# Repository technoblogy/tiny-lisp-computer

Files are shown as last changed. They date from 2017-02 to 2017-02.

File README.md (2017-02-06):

# Tiny Lisp Computer
A self-contained computer with its own display and keyboard, based on an ATmega328 or ATmega1284, that you can program in Lisp.
For more information see:

Tiny Lisp Computer (ATmega328): http://www.technoblogy.com/show?1GX1

Tiny Lisp Computer 2 (ATmega1284): http://www.technoblogy.com/show?1INT

Tiny Lisp Computer 2 PCB version: http://www.technoblogy.com/show?1KTO

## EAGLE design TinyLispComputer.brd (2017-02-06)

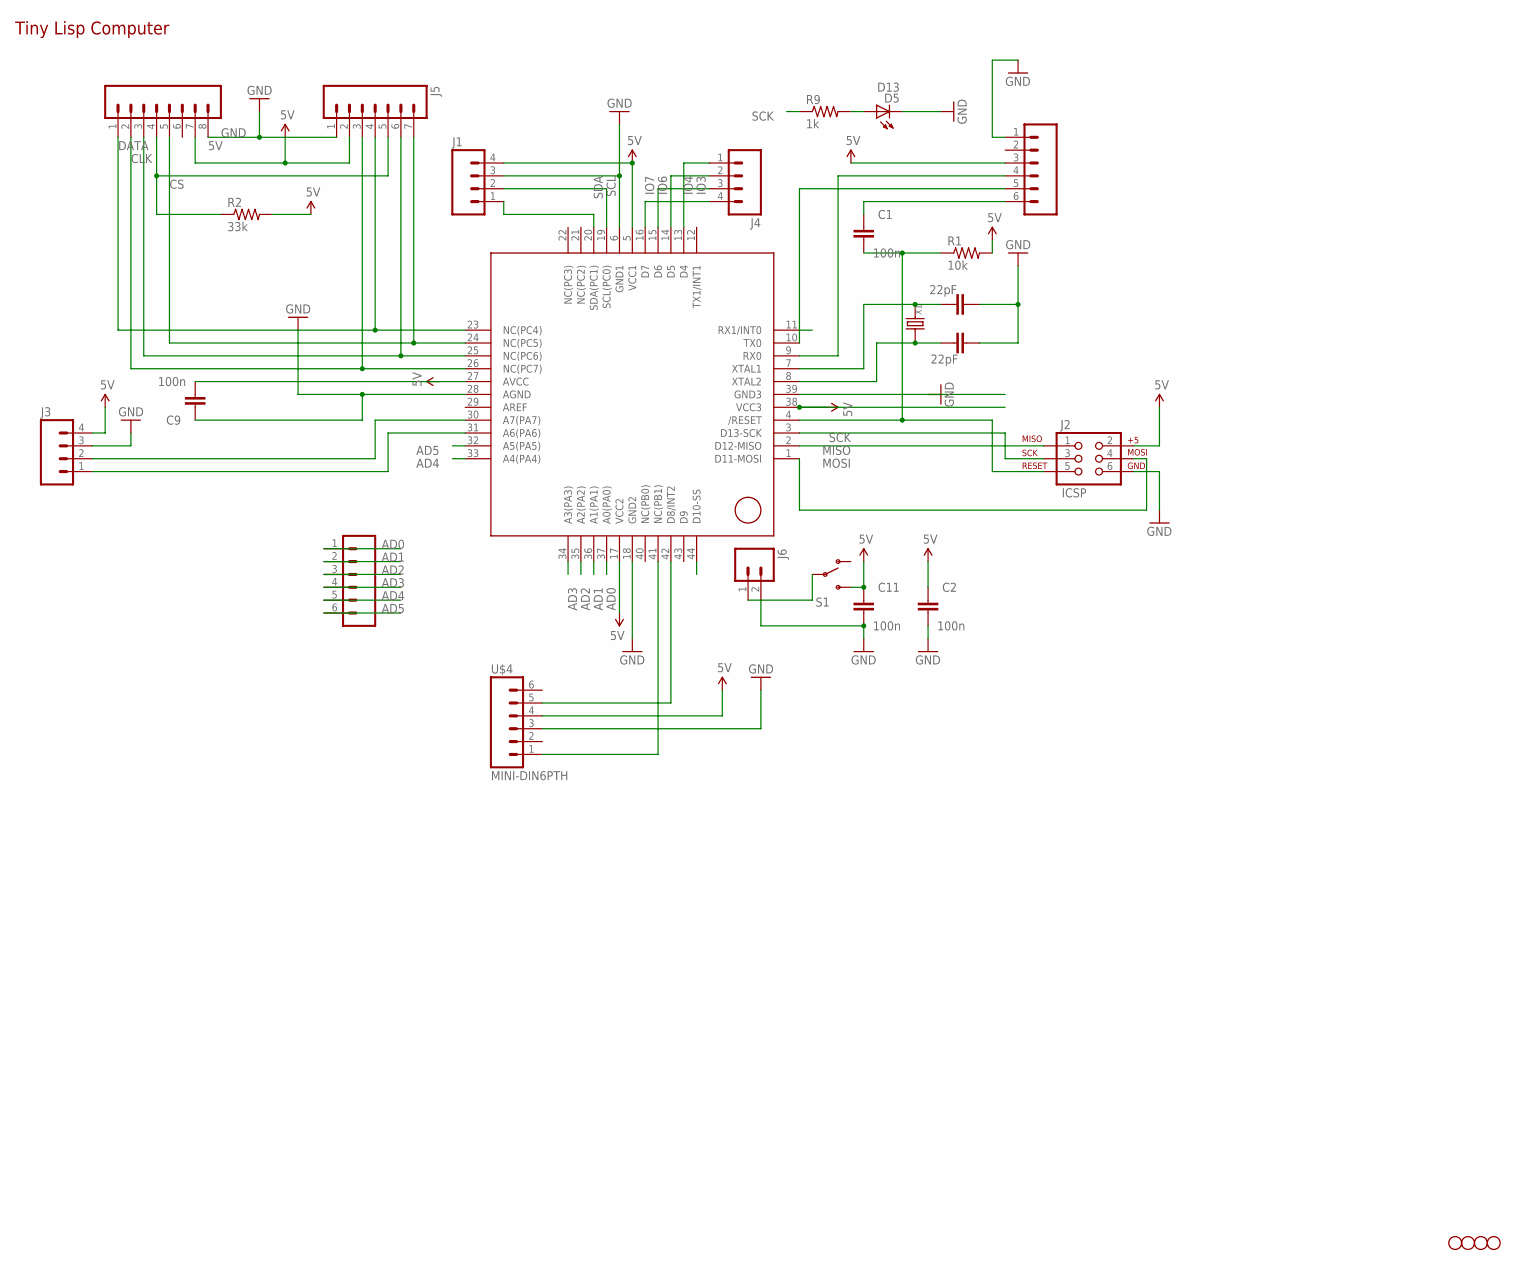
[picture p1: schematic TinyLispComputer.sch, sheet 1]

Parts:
C1, C2, C9, C11: 100n; 0603-CAP
C12, C13: 22pF; 0603-CAP
D5: D13; CHIPLED_0805
J1, J3, J4: M04LONGPADS; 1X04_LONGPADS
J2: ICSP; 2X3
J5: M07; 1X07
J6: M021X02_NO_SILK; 1X02_NO_SILK
JP1, JP11: M06LONGPADS; 1X06_LONGPADS
JP3, JP4, JP5, JP6: STAND-OFF
OLED: M08; 1X08_ROUND
R1: 10k; 0805
R2: 33k; 0805
R9: 1k; 0805
S1: SWITCH-SPDTPTH; SWITCH-SPDT
U3: ATMEGA1284P; TQFP44
U$4: MINI-DIN6PTH; MINI-DIN6
X1: CRYSTAL-0500290P1; 2P-SMD-5.0X3.2

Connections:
5V: C2.1, C9.2, C11.1, J1.4, J2.2, J3.4, J5.2, JP1.3, OLED.7, R1.2, R2.2, S1.3 (S), U3.5 (VCC1), U3.17 (VCC2), U3.27 (AVCC), U3.38 (VCC3), U$4.4
AD0: JP11.1, U3.37 (A0(PA0))
AD1: JP11.2, U3.36 (A1(PA1))
AD2: JP11.3, U3.35 (A2(PA2))
AD3: JP11.4, U3.34 (A3(PA3))
AD4: JP11.5, U3.33 (A4(PA4))
AD5: JP11.6, U3.32 (A5(PA5))
CLK: J5.6, OLED.3, U3.25 (NC(PC6))
CS: J5.4, OLED.1, U3.23 (NC(PC4))
DATA: J5.3, OLED.2, U3.26 (NC(PC7))
GND: C2.2, C9.1, C11.2, C12.1, C13.1, D5.C, J1.3, J2.6, J3.3, J5.1, J6.2, JP1.1, OLED.8, U3.6 (GND1), U3.18 (GND2), U3.28 (AGND), U3.39 (GND3), U$4.3
IO2: U3.11 (RX1/INT0)
IO3: J4.1, U3.13 (D4)
IO4: J4.2, U3.14 (D5)
IO6: J4.3, U3.15 (D6)
IO7: J4.4, U3.16 (D7)
MISO: J2.1, U3.2 (D12-MISO)
MOSI: J2.4, U3.1 (D11-MOSI)
unnamed: J5.7, OLED.5, U3.24 (NC(PC5))
unnamed: J6.1, S1.2
unnamed: C1.1, JP1.6
unnamed: J5.5, OLED.4, R2.1
unnamed: J3.1, U3.31 (A6(PA6))
unnamed: C1.2, J2.5, R1.1, U3.4 (/RESET)
unnamed: U3.42 (D8/INT2), U$4.5
unnamed: U3.41 (NC(PB1)), U$4.1
unnamed: J3.2, U3.30 (A7(PA7))
unnamed: D5.A, R9.2
unnamed: C13.2, U3.8 (XTAL2), X1.2
unnamed: C12.2, U3.7 (XTAL1), X1.1
RX-I: JP1.4, U3.9 (RX0)
SCK: J2.3, R9.1, U3.3 (D13-SCK)
SCL: J1.2, U3.19 (SCL(PC0))
SDA: J1.1, U3.20 (SDA(PC1))
SS: U3.44 (D10-SS)
TX-O: JP1.5, U3.10 (TX0)

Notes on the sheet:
Tiny Lisp Computer

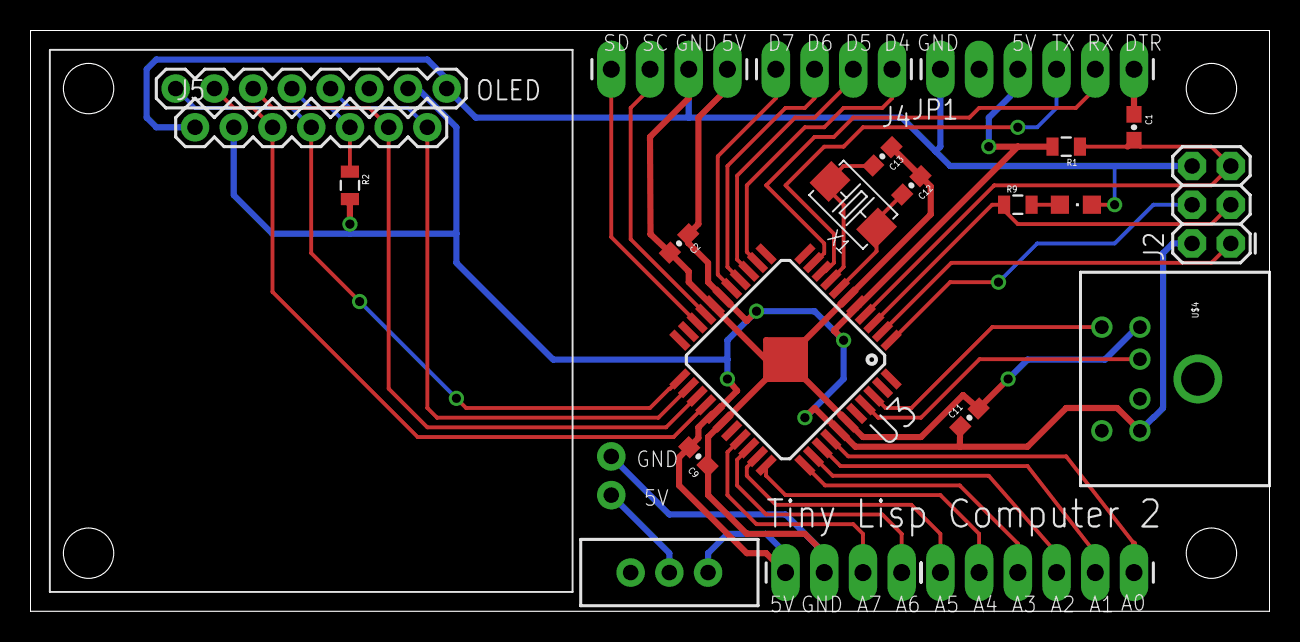
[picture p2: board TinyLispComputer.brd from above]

Board: 2 copper layers, 81.3 x 38.1 mm, 27 parts (0 on the bottom side), 34 nets.

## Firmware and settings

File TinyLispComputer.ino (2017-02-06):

 /* Tiny Lisp Computer 2 - uLisp 1.5
   David Johnson-Davies - www.technoblogy.com - 24th January 2017
    
   Licensed under the MIT license: https://opensource.org/licenses/MIT
*/

#include <setjmp.h>
#include <SPI.h>

// Compile options

#define checkoverflow
#define resetautorun
// #define printfreespace
#define serialmonitor
#define tinylispcomputer

// C Macros

#define nil                NULL
#define car(x)             (((object *) (x))->car)
#define cdr(x)             (((object *) (x))->cdr)

#define first(x)           (((object *) (x))->car)
#define second(x)          (car(cdr(x)))
#define cddr(x)            (cdr(cdr(x)))
#define third(x)           (car(cdr(cdr(x))))
#define fourth(x)          (car(cdr(cdr(cdr(x)))))

#define push(x, y)         ((y) = cons((x),(y)))
#define pop(y)             ((y) = cdr(y))

#define numberp(x)         ((x)->type == NUMBER)
#define stringp(x)         ((x)->type == STRING)
#define streamp(x)         ((x)->type == STREAM)
#define listp(x)           ((x) == NULL || (x)->type >= PAIR || (x)->type == ZERO)
#define consp(x)           (((x)->type >= PAIR || (x)->type == ZERO) && (x) != NULL)

#define mark(x)            (car(x) = (object *)(((unsigned int)(car(x))) | 0x8000))
#define unmark(x)          (car(x) = (object *)(((unsigned int)(car(x))) & 0x7FFF))
#define marked(x)          ((((unsigned int)(car(x))) & 0x8000) != 0)

// 1:Show GCs 2:show symbol addresses
// #define debug1
// #define debug2

// Constants
// RAMSTART, RAMEND, and E2END are defined by the processor's ioxxx.h file

const int RAMsize = RAMEND - RAMSTART + 1;
const int workspacesize = (RAMsize - RAMsize/4 - 280)/4;
const int EEPROMsize = E2END;

const int buflen = 17;  // Length of longest symbol + 1
enum type {ZERO, SYMBOL, NUMBER, STRING, STREAM, PAIR };  // PAIR must be last
enum token { UNUSED, BRA, KET, QUO, DOT };
enum stream { SERIALSTREAM, I2CSTREAM, SPISTREAM };

enum function { SYMBOLS, NIL, TEE, LAMBDA, LET, LETSTAR, CLOSURE, SPECIAL_FORMS, QUOTE, DEFUN, DEFVAR,
SETQ, LOOP, PUSH, POP, INCF, DECF, SETF, DOLIST, DOTIMES, FORMILLIS, WITHI2C, WITHSPI, TAIL_FORMS, PROGN,
RETURN, IF, COND, WHEN, UNLESS, AND, OR, FUNCTIONS, NOT, NULLFN, CONS, ATOM, LISTP, CONSP, NUMBERP,
STREAMP, EQ, CAR, FIRST, CDR, REST, CAAR, CADR, SECOND, CDAR, CDDR, CAAAR, CAADR, CADAR, CADDR, THIRD,
CDAAR, CDADR, CDDAR, CDDDR, LENGTH, LIST, REVERSE, NTH, ASSOC, MEMBER, APPLY, FUNCALL, APPEND, MAPC,
MAPCAR, ADD, SUBTRACT, MULTIPLY, DIVIDE, MOD, ONEPLUS, ONEMINUS, ABS, RANDOM, MAX, MIN, NUMEQ, LESS,
LESSEQ, GREATER, GREATEREQ, NOTEQ, PLUSP, MINUSP, ZEROP, ODDP, EVENP, STRINGP, STRINGEQ, SUBSEQ, LOGAND,
LOGIOR, LOGXOR, LOGNOT, ASH, LOGBITP, READ, EVAL, GLOBALS, LOCALS, MAKUNBOUND, BREAK, PRINT, PRINC,
WRITEBYTE, READBYTE, RESTARTI2C, GC, ROOM, SAVEIMAGE, LOADIMAGE, CLS, PINMODE, DIGITALREAD, DIGITALWRITE,
ANALOGREAD, ANALOGWRITE, DELAY, MILLIS, NOTE, EDIT, ENDFUNCTIONS };

// Typedefs

typedef struct sobject {
  union {
    struct {
      sobject *car;
      sobject *cdr;
    };
    struct {
      enum type type;
      union {
        unsigned int name;
        int integer;
      };
    };
  };
} object;

typedef object *(*fn_ptr_type)(object *, object *);

typedef struct {
  const char *string;
  fn_ptr_type fptr;
  int min;
  int max;
} tbl_entry_t;

// Global variables

jmp_buf exception;
object workspace[workspacesize];
unsigned int freespace = 0;
char ReturnFlag = 0;
object *freelist;
extern uint8_t _end;
int i2cCount;

object *GlobalEnv;
object *GCStack = NULL;
char buffer[buflen+1];
char BreakLevel = 0;
char LastChar = 0;
char LastPrint = 0;
volatile char Escape = 0;
char ExitEditor = 0;
char PrintReadably = 1;

// Forward references
object *tee;
object *tf_progn (object *form, object *env);
object *eval (object *form, object *env);
object *read ();
void repl(object *env);
void printobject (object *form);
char *lookupstring (unsigned int name);
int lookupfn (unsigned int name);
int builtin (char* n);
void Display (char c);

// Set up workspace

void initworkspace () {
  freelist = NULL;
  for (int i=workspacesize-1; i>=0; i--) {
    object *obj = &workspace[i];
    car(obj) = NULL;
    cdr(obj) = freelist;
    freelist = obj;
    freespace++;
  }
}

object *myalloc () {
  if (freespace == 0) error(F("No room"));
  object *temp = freelist;
  freelist = cdr(freelist);
  freespace--;
  return temp;
}

inline void myfree (object *obj) {
  car(obj) = NULL;
  cdr(obj) = freelist;
  freelist = obj;
  freespace++;
}

// Make each type of object

object *number (int n) {
  object *ptr = myalloc();
  ptr->type = NUMBER;
  ptr->integer = n;
  return ptr;
}

object *cons (object *arg1, object *arg2) {
  object *ptr = myalloc();
  ptr->car = arg1;
  ptr->cdr = arg2;
  return ptr;
}

object *symbol (unsigned int name) {
  object *ptr = myalloc();
  ptr->type = SYMBOL;
  ptr->name = name;
  return ptr;
}

object *stream (unsigned char streamtype, unsigned char address) {
  object *ptr = myalloc();
  ptr->type = STREAM;
  ptr->integer = streamtype<<8 | address;
  return ptr;
}

// Garbage collection

void markobject (object *obj) {
  MARK:
  if (obj == NULL) return;
  if (marked(obj)) return;

  object* arg = car(obj);
  int type = obj->type;
  mark(obj);
  
  if (type >= PAIR || type == ZERO) { // cons
    markobject(arg);
    obj = cdr(obj);
    goto MARK;
  }

  if (type == STRING) {
    obj = cdr(obj);
    while (obj != NULL) {
      arg = car(obj);
      mark(obj);
      obj = arg;
    }
  }
}

void sweep () {
  freelist = NULL;
  freespace = 0;
  for (int i=workspacesize-1; i>=0; i--) {
    object *obj = &workspace[i];
    if (!marked(obj)) myfree(obj); else unmark(obj);
  }
}

void gc (object *form, object *env) {
  #if defined(debug1)
  int start = freespace;
  #endif
  markobject(tee); 
  markobject(GlobalEnv);
  markobject(GCStack);
  markobject(form);
  markobject(env);
  sweep();
  #if defined(debug1)
  pchar('{');
  pint(freespace - start);
  pchar('}');
  #endif
}

// Save-image and load-image

typedef struct {
  unsigned int eval;
  unsigned int datasize;
  unsigned int globalenv;
  unsigned int tee;
  char data[];
} struct_image;

struct_image EEMEM image;

void movepointer (object *from, object *to) {
  for (int i=0; i<workspacesize; i++) {
    object *obj = &workspace[i];
    int type = (obj->type) & 0x7FFF;
    if (marked(obj) && type >= PAIR) {
      if (car(obj) == (object *)((unsigned int)from | 0x8000)) 
        car(obj) = (object *)((unsigned int)to | 0x8000);
      if (cdr(obj) == from) cdr(obj) = to;
    }
  }
}
  
int compactimage (object **arg) {
  markobject(tee);
  markobject(GlobalEnv);
  markobject(GCStack);
  object *firstfree = workspace;
  while (marked(firstfree)) firstfree++;

  for (int i=0; i<workspacesize; i++) {
    object *obj = &workspace[i];
    if (marked(obj) && firstfree < obj) {
      car(firstfree) = car(obj);
      cdr(firstfree) = cdr(obj);
      unmark(obj);
      movepointer(obj, firstfree);
      if (GlobalEnv == obj) GlobalEnv = firstfree;
      if (GCStack == obj) GCStack = firstfree;
      if (tee == obj) tee = firstfree;
      if (*arg == obj) *arg = firstfree;
      while (marked(firstfree)) firstfree++;
    }
  }
  sweep();
  return firstfree - workspace;
}
  
int saveimage (object *arg) {
  unsigned int imagesize = compactimage(&arg);
  // Save to EEPROM
  if ((imagesize*4+8) > EEPROMsize) {
    pfstring(F("Error: Image size too large: "));
    pint(imagesize+2); pln();
    GCStack = NULL;
    longjmp(exception, 1);
  }
  eeprom_write_word(&image.datasize, imagesize);
  eeprom_write_word(&image.eval, (unsigned int)arg);
  eeprom_write_word(&image.globalenv, (unsigned int)GlobalEnv);
  eeprom_write_word(&image.tee, (unsigned int)tee);
  eeprom_write_block(workspace, image.data, imagesize*4);
  return imagesize+2;
}

int loadimage () {
  unsigned int imagesize = eeprom_read_word(&image.datasize);
  if (imagesize == 0 || imagesize == 0xFFFF) error(F("No saved image"));
  GlobalEnv = (object *)eeprom_read_word(&image.globalenv);
  tee = (object *)eeprom_read_word(&image.tee) ;
  eeprom_read_block(workspace, image.data, imagesize*4);
  gc(NULL, NULL);
  return imagesize+2;
}

// Error handling

void error (const __FlashStringHelper *string) {
  pfstring(F("Error: "));
  pfstring(string); pln();
  GCStack = NULL;
  longjmp(exception, 1);
}

void error2 (object *symbol, const __FlashStringHelper *string) {
  pfstring(F("Error: '"));
  printobject(symbol);
  pfstring(F("' "));
  pfstring(string); pln();
  GCStack = NULL;
  longjmp(exception, 1);
}

// Helper functions

int toradix40 (int ch) {
  if (ch == 0) return 0;
  if (ch >= '0' && ch <= '9') return ch-'0'+30;
  ch = ch | 0x20;
  if (ch >= 'a' && ch <= 'z') return ch-'a'+1;
  error(F("Illegal character in symbol"));
  return 0;
}

int fromradix40 (int n) {
  if (n >= 1 && n <= 26) return 'a'+n-1;
  if (n >= 30 && n <= 39) return '0'+n-30;
  if (n == 27) return '-';
  return 0;
}

int pack40 (char *buffer) {
  return (((toradix40(buffer[0]) * 40) + toradix40(buffer[1])) * 40 + toradix40(buffer[2]));
}

int digitvalue (char d) {
  if (d>='0' && d<='9') return d-'0';
  d = d | 0x20;
  if (d>='a' && d<='f') return d-'a'+10;
  return 16;
}

char *name(object *obj){
  buffer[3] = '\0';
  if(obj->type != SYMBOL) error(F("Error in name"));
  unsigned int x = obj->name;
  if (x < ENDFUNCTIONS) return lookupstring(x);
  for (int n=2; n>=0; n--) {
    buffer[n] = fromradix40(x % 40);
    x = x / 40;
  }
  return buffer;
}

int integer(object *obj){
  if(obj->type != NUMBER) error(F("not a number"));
  return obj->integer;
}

int istream(object *obj){
  if(obj->type != STREAM) error(F("not a stream"));
  return obj->integer;
}

int issymbol(object *obj, unsigned int n) {
  return obj->type == SYMBOL && obj->name == n;
}

int eq (object *arg1, object *arg2) {
  int same_object = (arg1 == arg2);
  int same_symbol = (arg1->type == SYMBOL && arg2->type == SYMBOL && arg1->name == arg2->name);
  int same_number = (arg1->type == NUMBER && arg2->type == NUMBER && arg1->integer == arg2->integer);
  return (same_object || same_symbol || same_number);
}

// Lookup variable in environment

object *value(unsigned int n, object *env) {
  while (env != NULL) {
    object *item = car(env);
    if(car(item)->name == n) return item;
    env = cdr(env);
  }
  return nil;
}

object *findvalue (object *var, object *env) {
  unsigned int varname = var->name;
  object *pair = value(varname, env);
  if (pair == NULL) pair = value(varname, GlobalEnv);
  if (pair == NULL) error2(var,F("unknown variable"));
  return pair;
}

object *findtwin (object *var, object *env) {
  while (env != NULL) {
    object *pair = car(env);
    if (car(pair) == var) return pair;
    env = cdr(env);
  }
  return NULL;
}

object *closure (int tail, object *fname, object *state, object *function, object *args, object **env) {
  object *params = first(function);
  function = cdr(function);
  // Push state if not already in env
  while (state != NULL) {
    object *pair = first(state);
    if (findtwin(car(pair), *env) == NULL) push(first(state), *env);
    state = cdr(state);
  }
  // Add arguments to environment
  while (params != NULL && args != NULL) {
    object *var = first(params);
    object *value = first(args);
    if (tail) {
      object *pair = findtwin(var, *env);
      if (pair != NULL) cdr(pair) = value;
      else push(cons(var,value), *env);
    } else push(cons(var,value), *env);
    params = cdr(params);
    args = cdr(args);
  }
  if (params != NULL) error2(fname, F("has too few parameters"));
  if (args != NULL) error2(fname, F("has too many parameters"));
  // Do an implicit progn
  return tf_progn(function, *env); 
}

inline int listlength (object *list) {
  int length = 0;
  while (list != NULL) {
    list = cdr(list);
    length++;
  }
  return length;
}

inline int stringlength (object *form) {
  int length = 0;
  form = cdr(form);
  while (form != NULL) {
    int chars = form->integer;
    if (chars & 0xFF) length++;
    if (chars & 0xFF00) length++;
    form = car(form);
  }
  return length;
}

char character (object *string, int n) {
  object *arg = cdr(string);
  for (int i=0; i<(n>>1); i++) {
    if (arg == NULL) error(F("'subseq' index out of range"));
    arg = car(arg);
  }
  char ch;
  if (n&1) ch = (arg->integer) & 0xFF; else ch = (arg->integer)>>8 & 0xFF;
  if (ch == 0) error(F("'subseq' index out of range"));
  return ch;
}
  
object *apply (object *function, object *args, object **env) {
  if (function->type == SYMBOL) {
    unsigned int name = function->name;
    int nargs = listlength(args);
    if (name >= ENDFUNCTIONS) error2(function, F("is not a function"));
    if (nargs<lookupmin(name)) error2(function, F("has too few arguments"));
    if (nargs>lookupmax(name)) error2(function, F("has too many arguments"));
    return ((fn_ptr_type)lookupfn(name))(args, *env);
  }
  if (listp(function) && issymbol(car(function), LAMBDA)) {
    function = cdr(function);
    object *result = closure(1, NULL, NULL, function, args, env);
    return eval(result, *env);
  }
  if (listp(function) && issymbol(car(function), CLOSURE)) {
    function = cdr(function);
    object *result = closure(1, NULL, car(function), cdr(function), args, env);
    return eval(result, *env);
  }
  error2(function, F("illegal function"));
  return NULL;
}

// In-place operations

object **place (object *args, object *env) {
  if (!consp(args)) return &cdr(findvalue(args, env));
  object* function = first(args);
  if (issymbol(function, CAR) || issymbol(function, FIRST)) {
    object *value = eval(second(args), env);
    if (!listp(value)) error(F("Can't take car"));
    return &car(value);
  }
  if (issymbol(function, CDR) || issymbol(function, REST)) {
    object *value = eval(second(args), env);
    if (!listp(value)) error(F("Can't take cdr"));
    return &cdr(value);
  }
  if (issymbol(function, NTH)) {
    int index = integer(eval(second(args), env));
    object *list = eval(third(args), env);
    if (!consp(list)) error(F("'nth' second argument is not a list"));
    while (index > 0) {
      list = cdr(list);
      if (list == NULL) error(F("'nth' index out of range"));
      index--;
    }
    return &car(list);
  }
  error(F("Illegal place"));
  return nil;
}

// Checked car and cdr

inline object *carx (object *arg) {
  if (!listp(arg)) error(F("Can't take car"));
  if (arg == nil) return nil;
  return car(arg);
}

inline object *cdrx (object *arg) {
  if (!listp(arg)) error(F("Can't take cdr"));
  if (arg == nil) return nil;
  return cdr(arg);
}

// I2C interface

#if defined(__AVR_ATmega328P__)
uint8_t const TWI_SDA_PIN = 18;
uint8_t const TWI_SCL_PIN = 19;
#elif defined(__AVR_ATmega1280__) || defined(__AVR_ATmega2560__)
uint8_t const TWI_SDA_PIN = 20;
uint8_t const TWI_SCL_PIN = 21;
#elif defined(__AVR_ATmega644P__) || defined(__AVR_ATmega1284P__)
uint8_t const TWI_SDA_PIN = 17;
uint8_t const TWI_SCL_PIN = 16;
#elif defined(__AVR_ATmega32U4__)
uint8_t const TWI_SDA_PIN = 6;
uint8_t const TWI_SCL_PIN = 5;
#endif

uint32_t const F_TWI = 400000L;  // Hardware I2C clock in Hz
uint8_t const TWSR_MTX_DATA_ACK = 0x28;
uint8_t const TWSR_MTX_ADR_ACK = 0x18;
uint8_t const TWSR_MRX_ADR_ACK = 0x40;
uint8_t const TWSR_START = 0x08;
uint8_t const TWSR_REP_START = 0x10;
uint8_t const I2C_READ = 1;
uint8_t const I2C_WRITE = 0;

void I2Cinit(bool enablePullup) {
  TWSR = 0;                        // no prescaler
  TWBR = (F_CPU/F_TWI - 16)/2;     // set bit rate factor
  if (enablePullup) {
    digitalWrite(TWI_SDA_PIN, HIGH);
    digitalWrite(TWI_SCL_PIN, HIGH);
  }
}

uint8_t I2Cread(uint8_t last) {
  TWCR = 1<<TWINT | 1<<TWEN | (last ? 0 : (1<<TWEA));
  while (!(TWCR & 1<<TWINT));
  return TWDR;
}

bool I2Cwrite(uint8_t data) {
  TWDR = data;
  TWCR = 1<<TWINT | 1 << TWEN;
  while (!(TWCR & 1<<TWINT));
  return (TWSR & 0xF8) == TWSR_MTX_DATA_ACK;
}

bool I2Cstart(uint8_t addressRW) {
  TWCR = 1<<TWINT | 1<<TWSTA | 1<<TWEN;    // send START condition
  while (!(TWCR & 1<<TWINT));
  if ((TWSR & 0xF8) != TWSR_START && (TWSR & 0xF8) != TWSR_REP_START) return false;
  TWDR = addressRW;  // send device address and direction
  TWCR = 1<<TWINT | 1<<TWEN;
  while (!(TWCR & 1<<TWINT));
  if (addressRW & I2C_READ) return (TWSR & 0xF8) == TWSR_MRX_ADR_ACK;
  else return (TWSR & 0xF8) == TWSR_MTX_ADR_ACK;
}

bool I2Crestart(uint8_t addressRW) {
  return I2Cstart(addressRW);
}

void I2Cstop(void) {
  TWCR = 1<<TWINT | 1<<TWEN | 1<<TWSTO;
  while (TWCR & 1<<TWSTO); // wait until stop and bus released
}

// Special forms

object *sp_quote (object *args, object *env) {
  (void) env;
  return first(args);
}

object *sp_defun (object *args, object *env) {
  (void) env;
  object *var = first(args);
  if (var->type != SYMBOL) error2(var, F("is not a symbol"));
  object *val = cons(symbol(LAMBDA), cdr(args));
  object *pair = value(var->name,GlobalEnv);
  if (pair != NULL) { cdr(pair) = val; return var; }
  push(cons(var, val), GlobalEnv);
  return var;
}

object *sp_defvar (object *args, object *env) {
  object *var = first(args);
  if (var->type != SYMBOL) error2(var, F("is not a symbol"));
  object *val = eval(second(args), env);
  object *pair = value(var->name,GlobalEnv);
  if (pair != NULL) { cdr(pair) = val; return var; }
  push(cons(var, val), GlobalEnv);
  return var;
}

object *sp_setq (object *args, object *env) {
  object *arg = eval(second(args), env);
  object *pair = findvalue(first(args), env);
  cdr(pair) = arg;
  return arg;
}

object *sp_loop (object *args, object *env) {
  ReturnFlag = 0;
  object *start = args;
  for (;;) {
    args = start;
    while (args != NULL) {
      object *form = car(args);
      object *result = eval(form,env);
      if (ReturnFlag == 1) {
        ReturnFlag = 0;
        return result;
      }
      args = cdr(args);
    }
  }
}

object *sp_push (object *args, object *env) {
  object *item = eval(first(args), env);
  object **loc = place(second(args), env);
  push(item, *loc);
  return *loc;
}

object *sp_pop (object *args, object *env) {
  object **loc = place(first(args), env);
  object *result = car(*loc);
  pop(*loc);
  return result;
}

object *sp_incf (object *args, object *env) {
  object **loc = place(first(args), env);
  int increment = 1;
  int result = integer(*loc);
  args = cdr(args);
  if (args != NULL) increment = integer(eval(first(args), env));
  #if defined(checkoverflow)
  if (increment < 1) { if (-32768 - increment > result) error(F("'incf' arithmetic overflow")); }
  else { if (32767 - increment < result) error(F("'incf' arithmetic overflow")); }
  #endif
  result = result + increment;
  *loc = number(result);
  return *loc;
}

object *sp_decf (object *args, object *env) {
  object **loc = place(first(args), env);
  int decrement = 1;
  int result = integer(*loc);
  args = cdr(args);
  if (args != NULL) decrement = integer(eval(first(args), env));
  #if defined(checkoverflow)
  if (decrement < 1) { if (32767 + decrement < result) error(F("'decf' arithmetic overflow")); }
  else { if (-32768 + decrement > result) error(F("'decf' arithmetic overflow")); }
  #endif
  result = result - decrement;
  *loc = number(result);
  return *loc;
}

object *sp_setf (object *args, object *env) {
  object **loc = place(first(args), env);
  object *result = eval(second(args), env);
  *loc = result;
  return result;
}

object *sp_dolist (object *args, object *env) {
  object *params = first(args);
  object *var = first(params);
  object *result = nil;
  object *list = eval(second(params), env);
  if (!listp(list)) error(F("'dolist' argument is not a list"));
  push(list, GCStack); // Don't GC the list
  object *pair = cons(var,nil);
  push(pair,env);
  params = cdr(cdr(params));
  if (params != NULL) result = car(params);
  object *forms = cdr(args);
  while (list != NULL) {
    cdr(pair) = first(list);
    list = cdr(list);
    eval(tf_progn(forms,env), env);
  }
  cdr(pair) = nil;
  pop(GCStack);
  return eval(result, env);
}

object *sp_dotimes (object *args, object *env) {
  object *params = first(args);
  object *var = first(params);
  object *result = nil;
  int count = integer(eval(second(params), env));
  int index = 0;
  params = cdr(cdr(params));
  if (params != NULL) result = car(params);
  object *pair = cons(var,number(0));
  push(pair,env);
  object *forms = cdr(args);
  while (index < count) {
    cdr(pair) = number(index);
    index++;
    eval(tf_progn(forms,env), env);
  }
  cdr(pair) = number(index);
  return eval(result, env);
}

object *sp_formillis (object *args, object *env) {
  object *param = first(args);
  unsigned long start = millis();
  unsigned long now, total = 0;
  if (param != NULL) total = integer(first(param));
  eval(tf_progn(cdr(args),env), env);
  do now = millis() - start; while (now < total);
  if (now <= 32767) return number(now);
  return nil;
}

object *sp_withi2c (object *args, object *env) {
  object *params = first(args);
  object *var = first(params);
  int address = integer(eval(second(params), env));
  params = cddr(params);
  int read = 0; // Write
  i2cCount = 0;
  if (params != NULL) {
    object *rw = eval(first(params), env);
    if (numberp(rw)) i2cCount = integer(rw);
    read = (rw != NULL);
  }
  I2Cinit(1); // Pullups
  object *pair = cons(var, (I2Cstart(address<<1 | read)) ? stream(I2CSTREAM, address) : nil);
  push(pair,env);
  object *forms = cdr(args);
  object *result = eval(tf_progn(forms,env), env);
  I2Cstop();
  return result;
}
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
void loop() {
  if (!setjmp(exception)) {
    #if defined(resetautorun)
    object *autorun = (object *)eeprom_read_word(&image.eval);
    if (autorun != NULL && (unsigned int)autorun != 0xFFFF) {
      loadimage();
      apply(autorun, NULL, NULL);
    }
    #endif
  }
  repl(NULL);
}

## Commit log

2016-10-18 Tiny Lisp Computer 2 - 18th October 2016
    Includes: ATmega1284 support, parenthesis matching, optional program entry via the Arduino IDE serial monitor, and a built-in program editor.
2017-02-06 Eagle files - Version 1
    [TinyLispComputer.brd, TinyLispComputer.sch]

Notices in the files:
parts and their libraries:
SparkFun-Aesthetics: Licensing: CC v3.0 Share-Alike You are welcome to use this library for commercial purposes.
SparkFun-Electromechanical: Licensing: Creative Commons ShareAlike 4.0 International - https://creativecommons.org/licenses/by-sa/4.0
